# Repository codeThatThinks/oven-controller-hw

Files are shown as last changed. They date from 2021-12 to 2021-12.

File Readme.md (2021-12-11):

# MLL Electronics Oven Controller v1.0

A Raspberry Pi Zero-powered PID reflow oven controller -- PCB design files.

## Controller PCBA

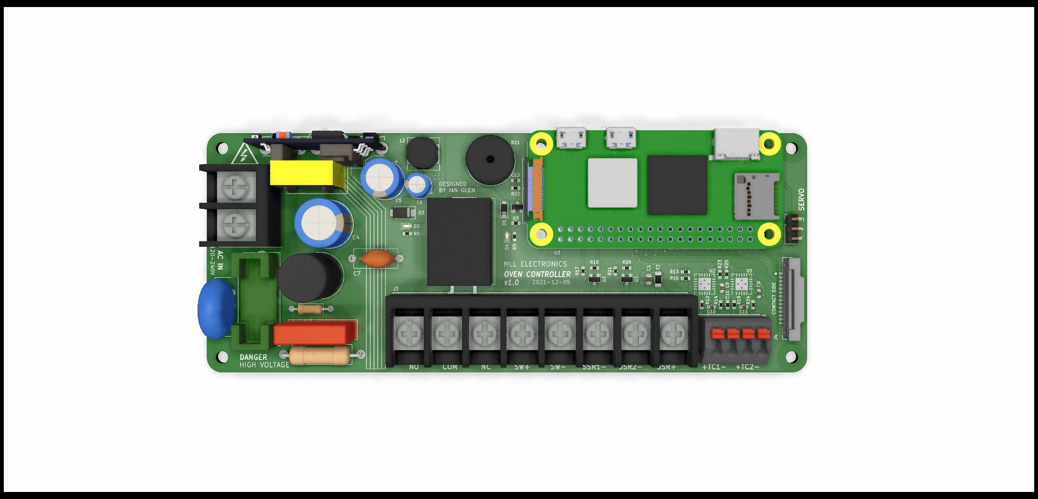
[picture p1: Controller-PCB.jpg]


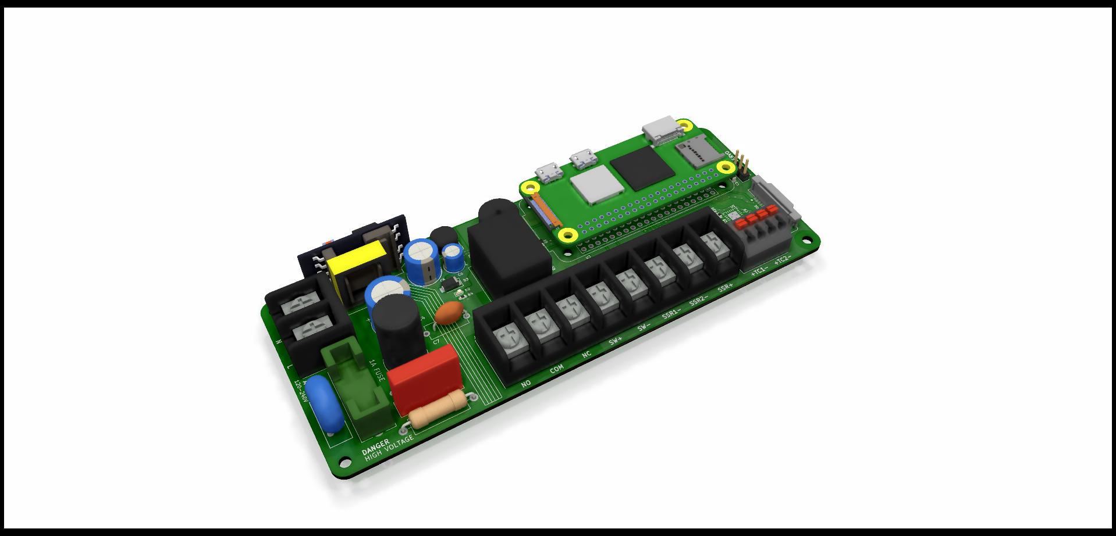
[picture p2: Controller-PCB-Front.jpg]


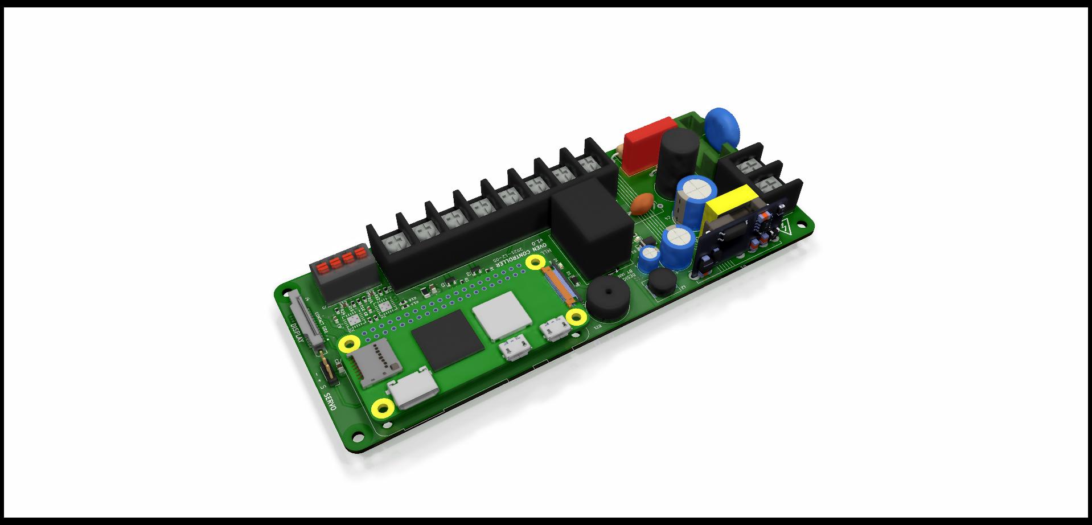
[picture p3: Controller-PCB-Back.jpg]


## Display PCBA

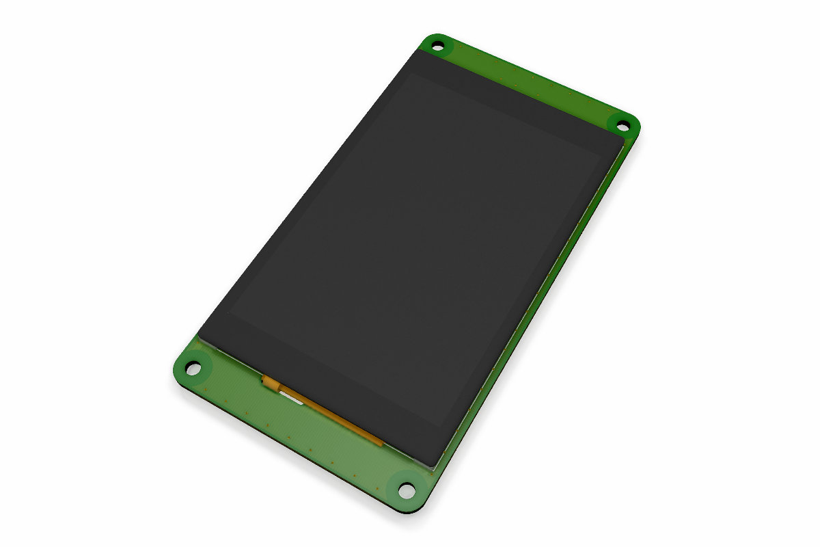
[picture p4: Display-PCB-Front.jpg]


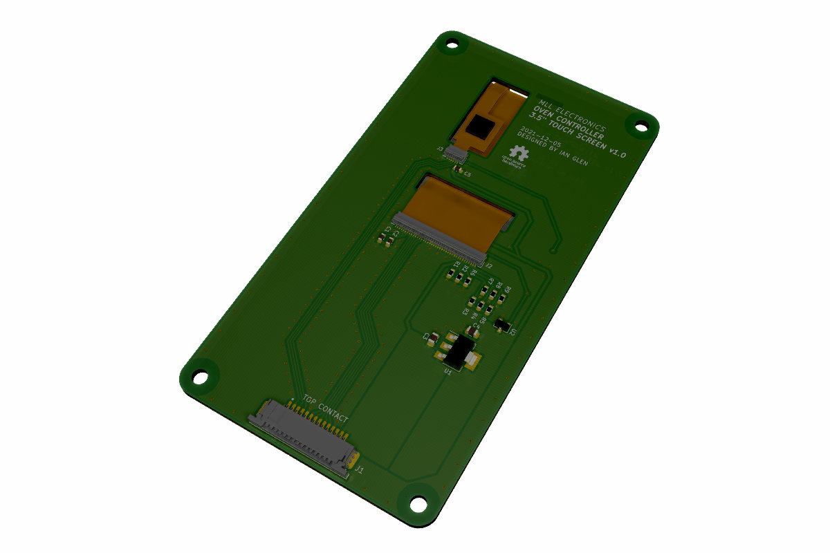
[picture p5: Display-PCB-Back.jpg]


## License

This project is licensed under the CERN-OHL-W v2. See LICENSE for more details.

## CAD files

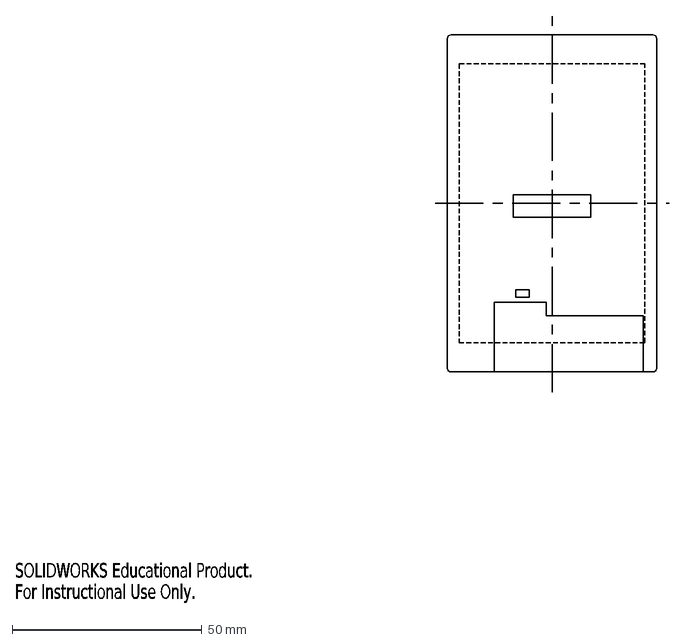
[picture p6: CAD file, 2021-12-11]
solidworks/LiangHaoHai 3.5 IPS TFT CTP Connector Cutout Locations.DXF
SOLIDWORKS Educational Product.
For Instructional Use Only.

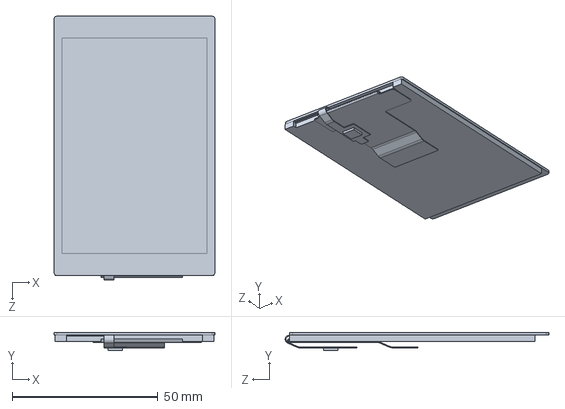
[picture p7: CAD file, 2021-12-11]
solidworks/LiangHaoHai 3.5 IPS TFT CTP.SLDPRT
55.2 x 6.20 x 90.4 mm

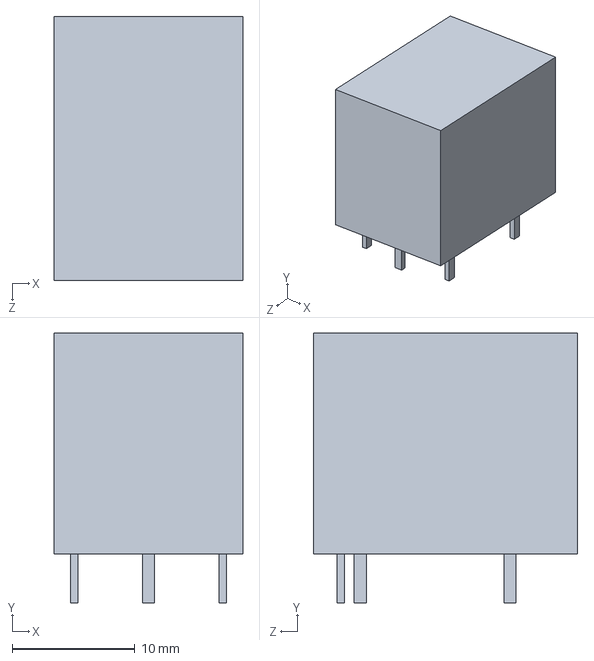
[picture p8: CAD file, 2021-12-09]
solidworks/Relay_SPDT_Omron-G5LE-1.SLDPRT
15.4 x 22.0 x 21.5 mm

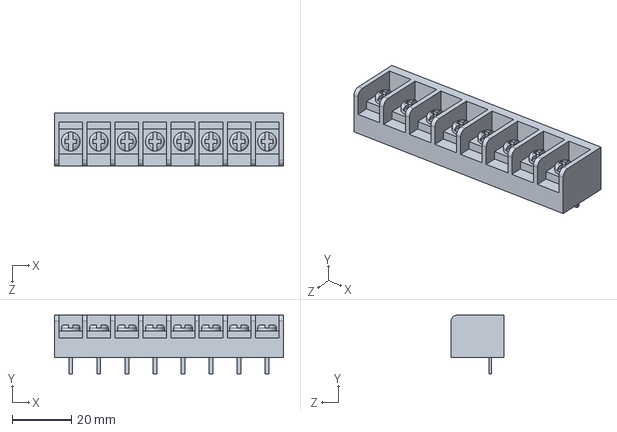
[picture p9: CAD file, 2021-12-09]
solidworks/TerminalBlock_OST_OSTYK44108030_P9.50mm.SLDPRT
77.4 x 19.9 x 17.9 mm

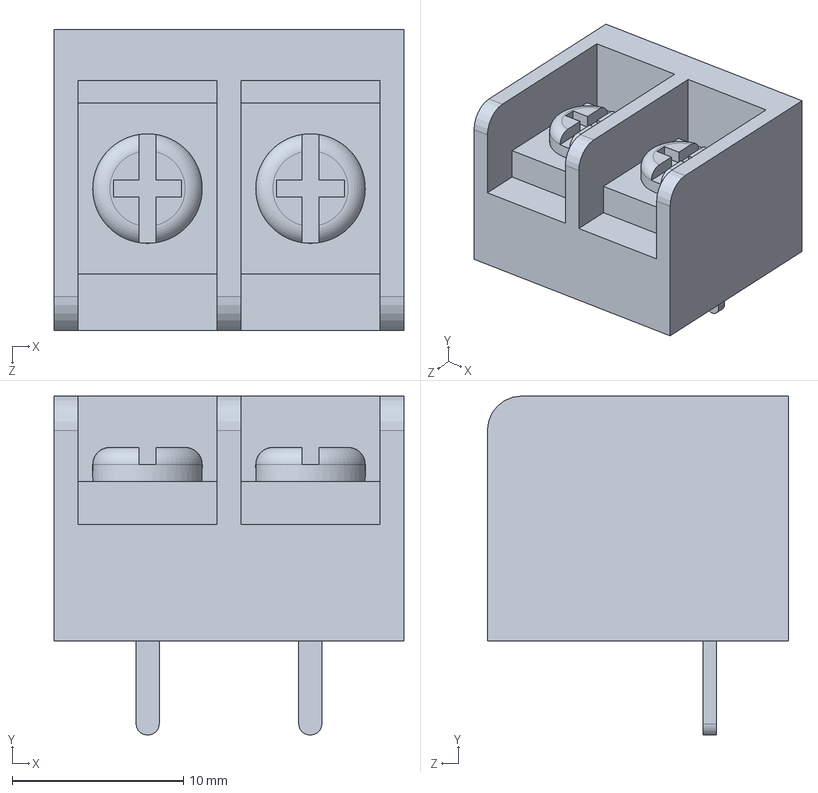
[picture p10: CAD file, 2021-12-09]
solidworks/TerminalBlock_Amphenol_YK-44102_P9.50mm.SLDPRT
20.4 x 19.8 x 17.6 mm

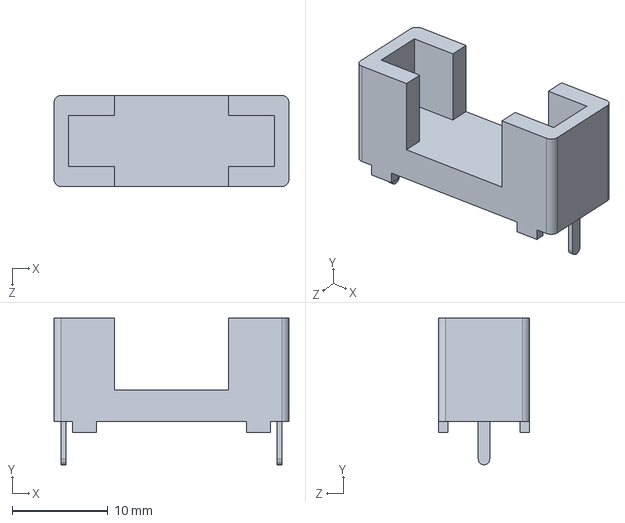
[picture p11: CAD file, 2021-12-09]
solidworks/Fuseholder_Cylinder-5x20mm_Littelfuse_0PTF0078P.SLDPRT
24.5 x 15.3 x 9.50 mm

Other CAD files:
solidworks/LiangHaoHai 3.5 IPS TFT CTP.DXF
solidworks/LiangHaoHai 3.5 IPS TFT CTP.SLDDRW

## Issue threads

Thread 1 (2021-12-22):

SCK and DC pins are swapped on display

codeThatThinks, 2021-12-22:
The pinout on the AliExpress listing has a typo. On the 40-pin FPC, pin 10 should be `RS/SPI_A0` and pin 11 should be `WR/SPI_SCK`.

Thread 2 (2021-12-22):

Increase PCB cutout around CTP FPC cable

codeThatThinks, 2021-12-22:
Increase clearance of the PCB cutout on the display by about 1mm on the right side (looking from the back side of the board). Left side clearance can be decreased by 0.5mm.

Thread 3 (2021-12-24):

Missing EEPROM address 0x30 on schematic

codeThatThinks, 2021-12-24:
AT34C04 eeprom also responds to 0x30 address for write protected writes. No conflict with other devices, but it is missing from the schematic.

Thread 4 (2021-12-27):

Wrong I2C addresses listed on schematic for MCP9601

codeThatThinks, 2021-12-27:
Addresses should be `1100 000x` (0x60) and `1100 001x` (0x61)

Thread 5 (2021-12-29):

MCP960x won't work on hardware I2C busses due to clock stretching bug

codeThatThinks, 2021-12-29:
MCP960x requires clock stretching for all register operations. Pi Zero 2 W has the same SoC as the Pi 3 and therefore does not properly implement clock stretching on hardware I2C busses. MCP960x should be put on its own bitbanged I2C bus using `i2c-gpio`. Use GPIO15 and GPIO18. External 4.7k pullups need to be added on those pins.

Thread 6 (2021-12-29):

Switch EEPROM out for NOR flash for non-volatile storage

codeThatThinks, 2021-12-29:
User settings were supposed to be stored on the I2C EEPROM, however the AT34 does not use the same addressing scheme as the AT24, therefore the kernel driver can only access the first 2KB. The driver also does not support mounting as a block device. A larger NOR flash could be placed on SPI1 and have the same write cycle life but be mountable as a /dev/mtd* device.

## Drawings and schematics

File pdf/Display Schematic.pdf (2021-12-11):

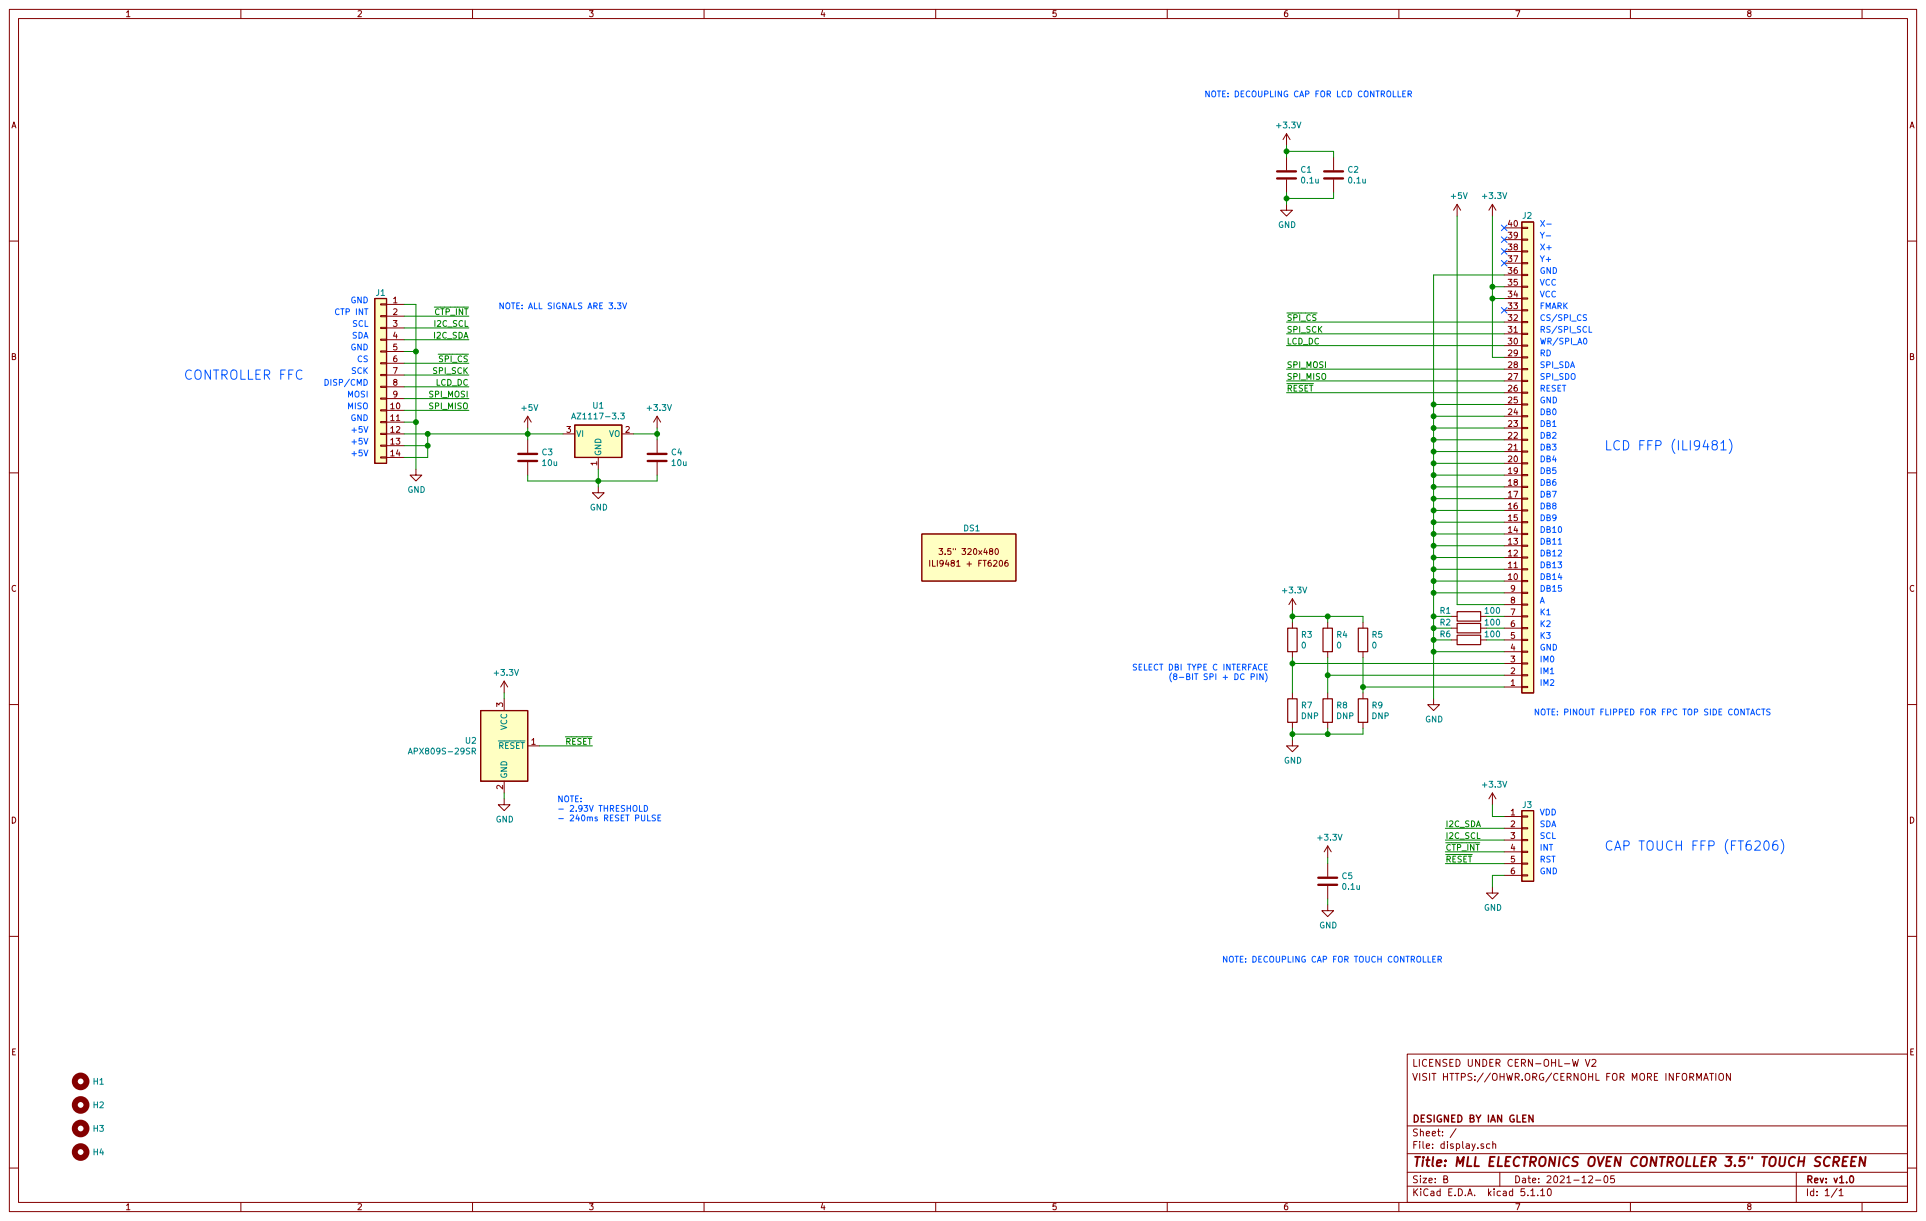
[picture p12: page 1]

DB6 GND GND MOSI MISO
CTP INT SDA

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
NOTE: DECOUPLING CAP FOR TOUCH CONTROLLER

LICENSED UNDER CERN-OHL-W V2
VISIT HTTPS://OHWR.ORG/CERNOHL FOR MORE INFORMATION

File: display.sch Sheet: / DESIGNED BY IAN GLEN

Id: 1/1 Title: MLL ELECTRONICS OVEN CONTROLLER 3.5" TOUCH SCREEN

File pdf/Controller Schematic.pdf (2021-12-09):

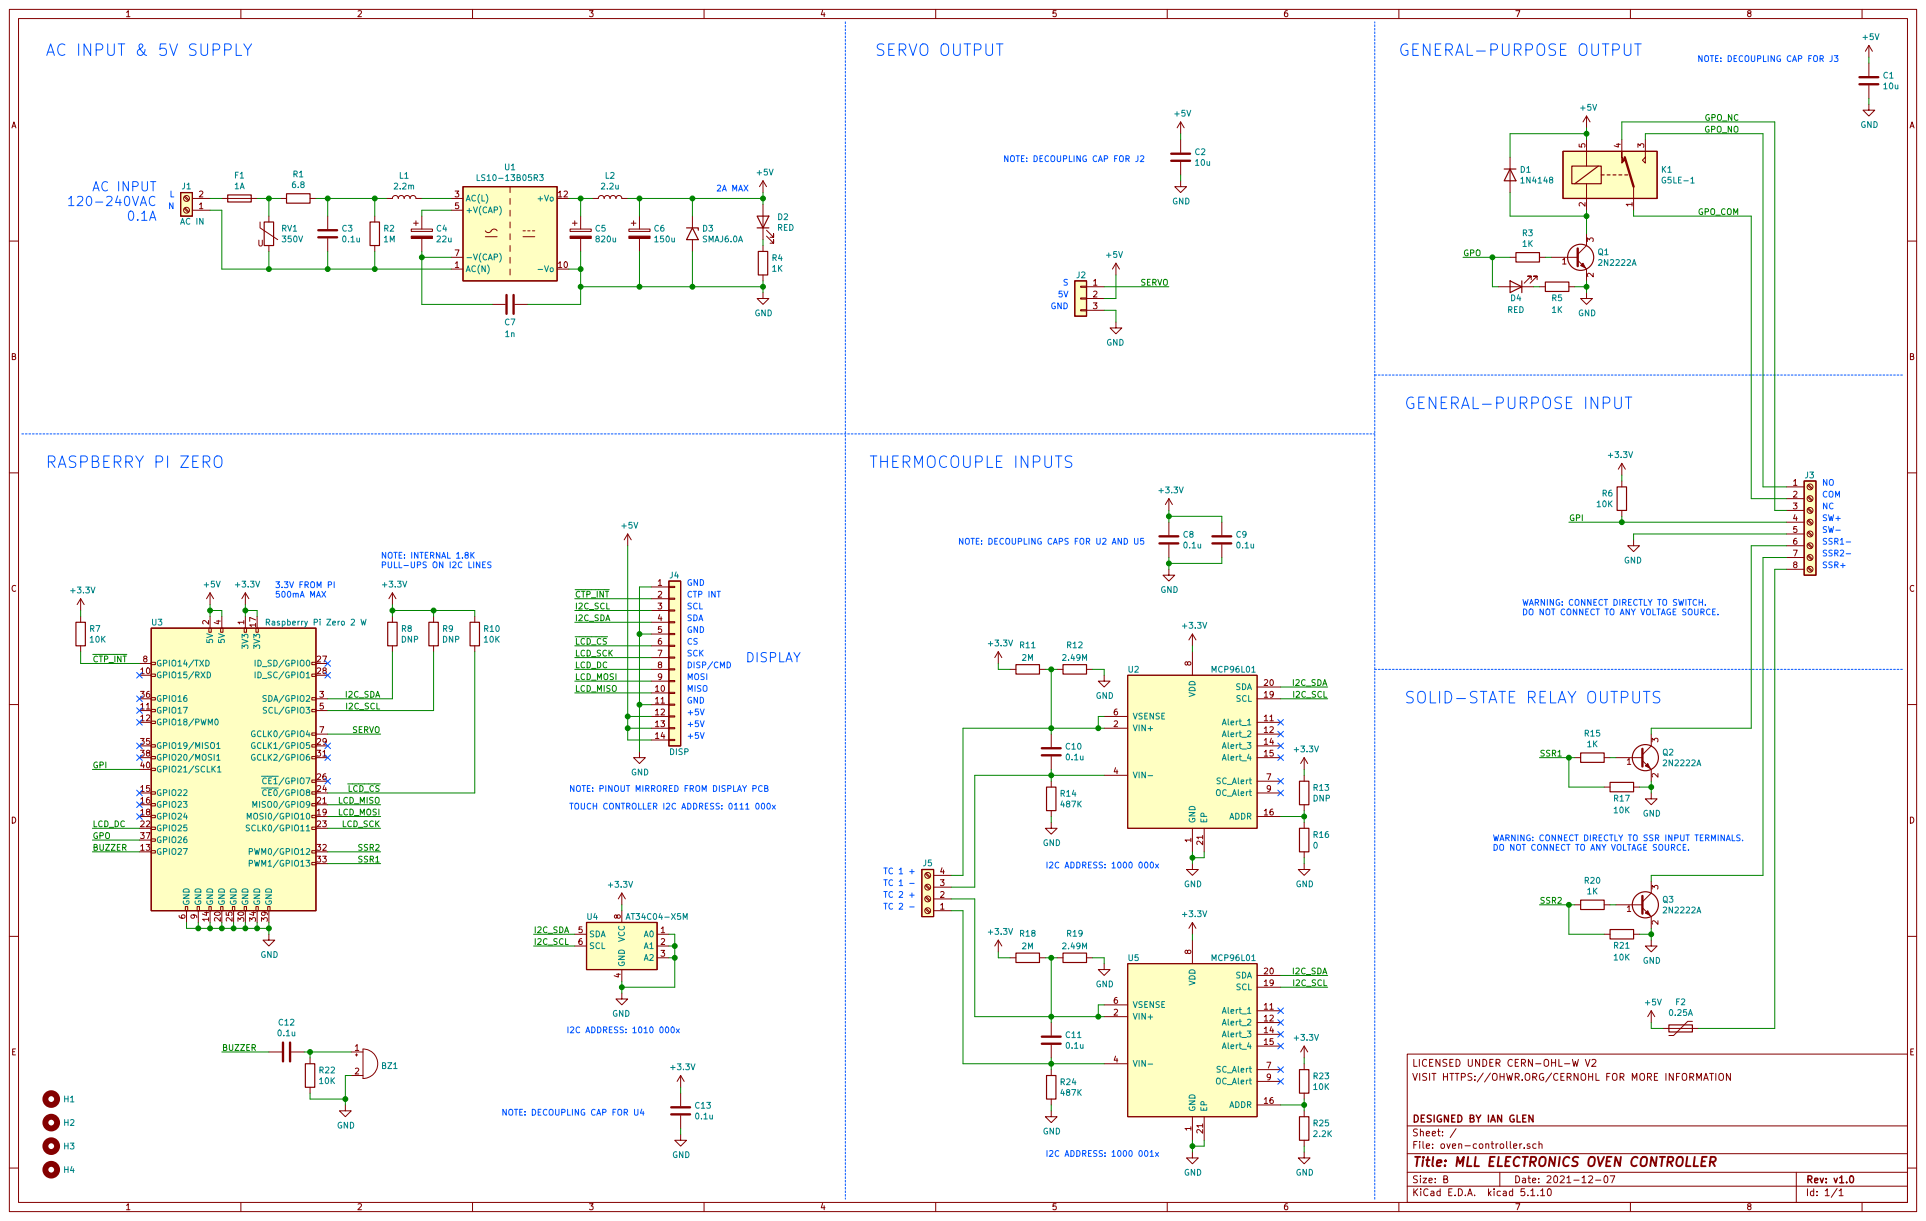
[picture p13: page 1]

NOTE: DECOUPLING CAP FOR J2

TOUCH CONTROLLER I2C ADDRESS: 0111 000x RASPBERRY PI ZERO

NOTE: INTERNAL 1.8K
PULL-UPS ON I2C LINES

1 Alert_1 11 Alert_2 12 Alert_3 14 Alert_4 15 ADDR 16 SCL 19 VIN+ 2 SDA 20 VIN- 4 VSENSE 6 SC_Alert 7 VDD

SOLID-STATE RELAY OUTPUTS

13
14

LICENSED UNDER CERN-OHL-W V2
VISIT HTTPS://OHWR.ORG/CERNOHL FOR MORE INFORMATION

File: oven-controller.sch Sheet: / DESIGNED BY IAN GLEN

Id: 1/1 Title: MLL ELECTRONICS OVEN CONTROLLER

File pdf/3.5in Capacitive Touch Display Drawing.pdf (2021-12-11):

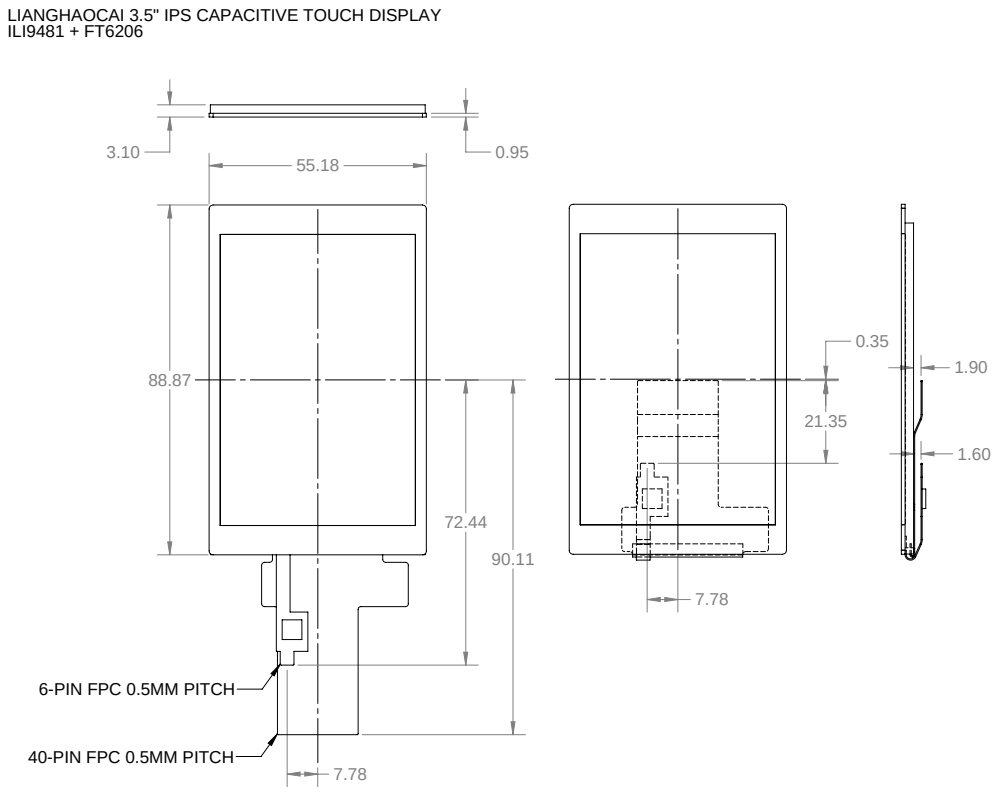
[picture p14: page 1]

LIANGHAOCAI 3.5" IPS CAPACITIVE TOUCH DISPLAY
ILI9481 + FT6206

6-PIN FPC 0.5MM PITCH

40-PIN FPC 0.5MM PITCH

CONNECTOR AND CUTOUT LOCATIONS

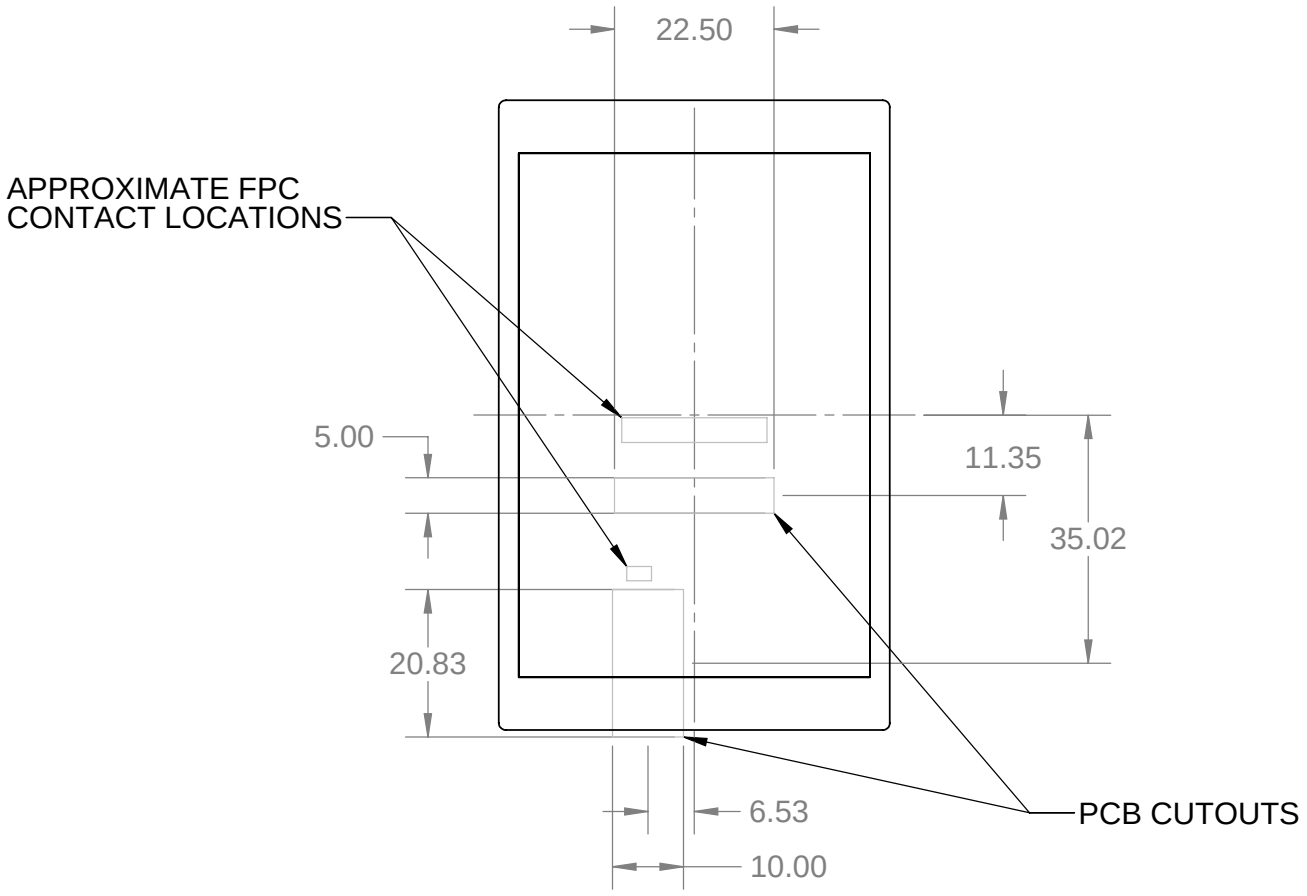
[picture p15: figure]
PCB CUTOUTS; APPROXIMATE FPC CONTACT LOCATIONS

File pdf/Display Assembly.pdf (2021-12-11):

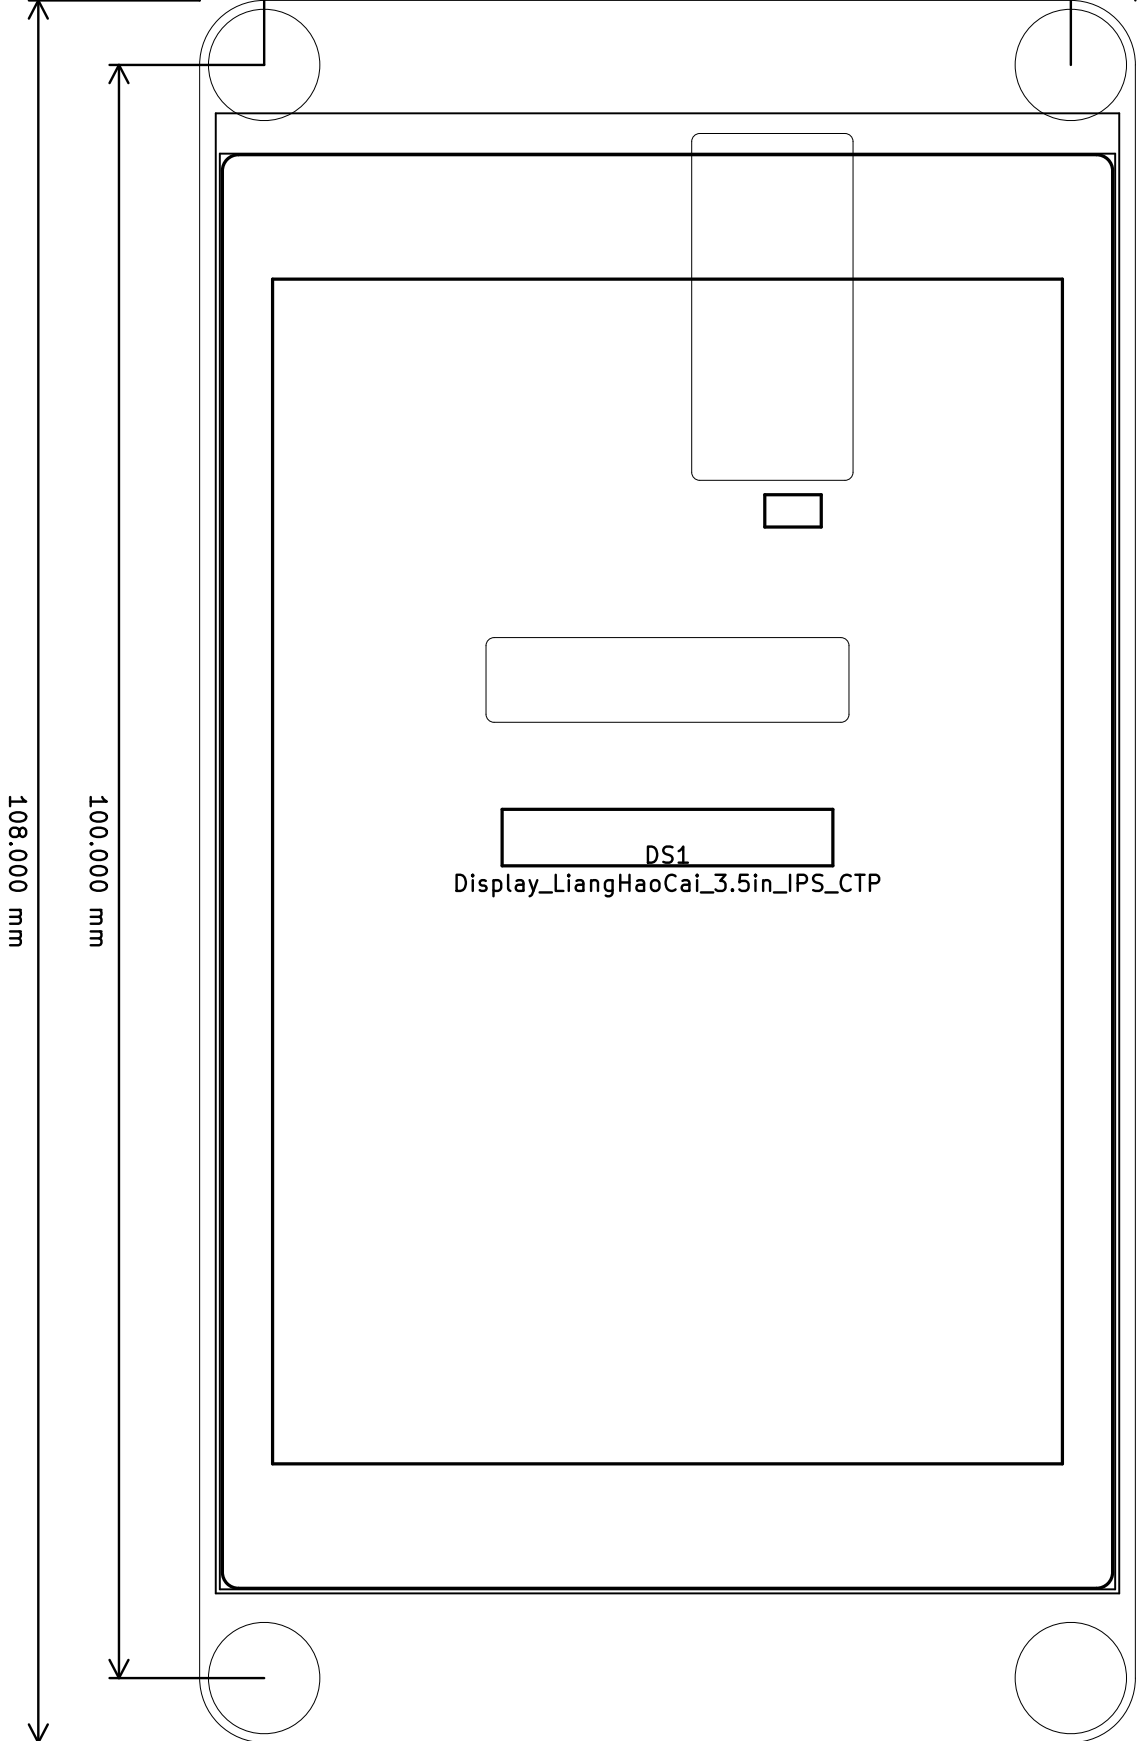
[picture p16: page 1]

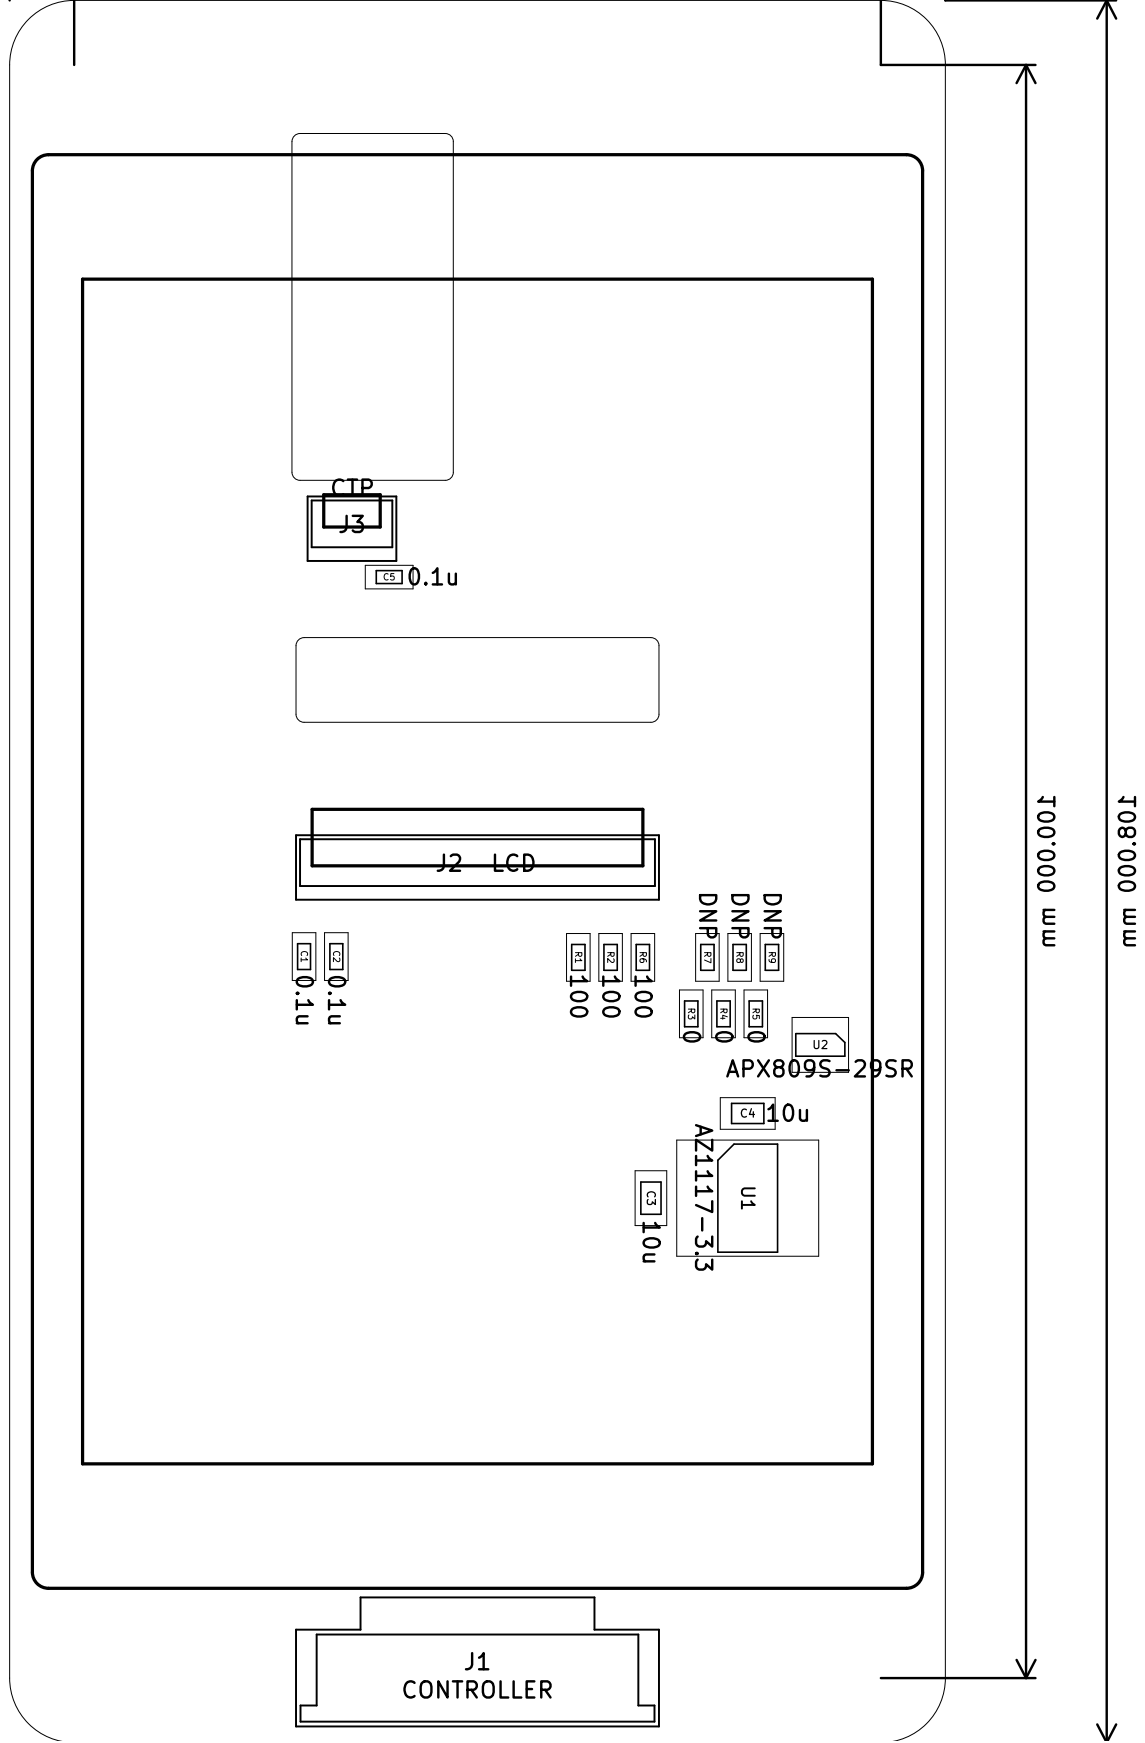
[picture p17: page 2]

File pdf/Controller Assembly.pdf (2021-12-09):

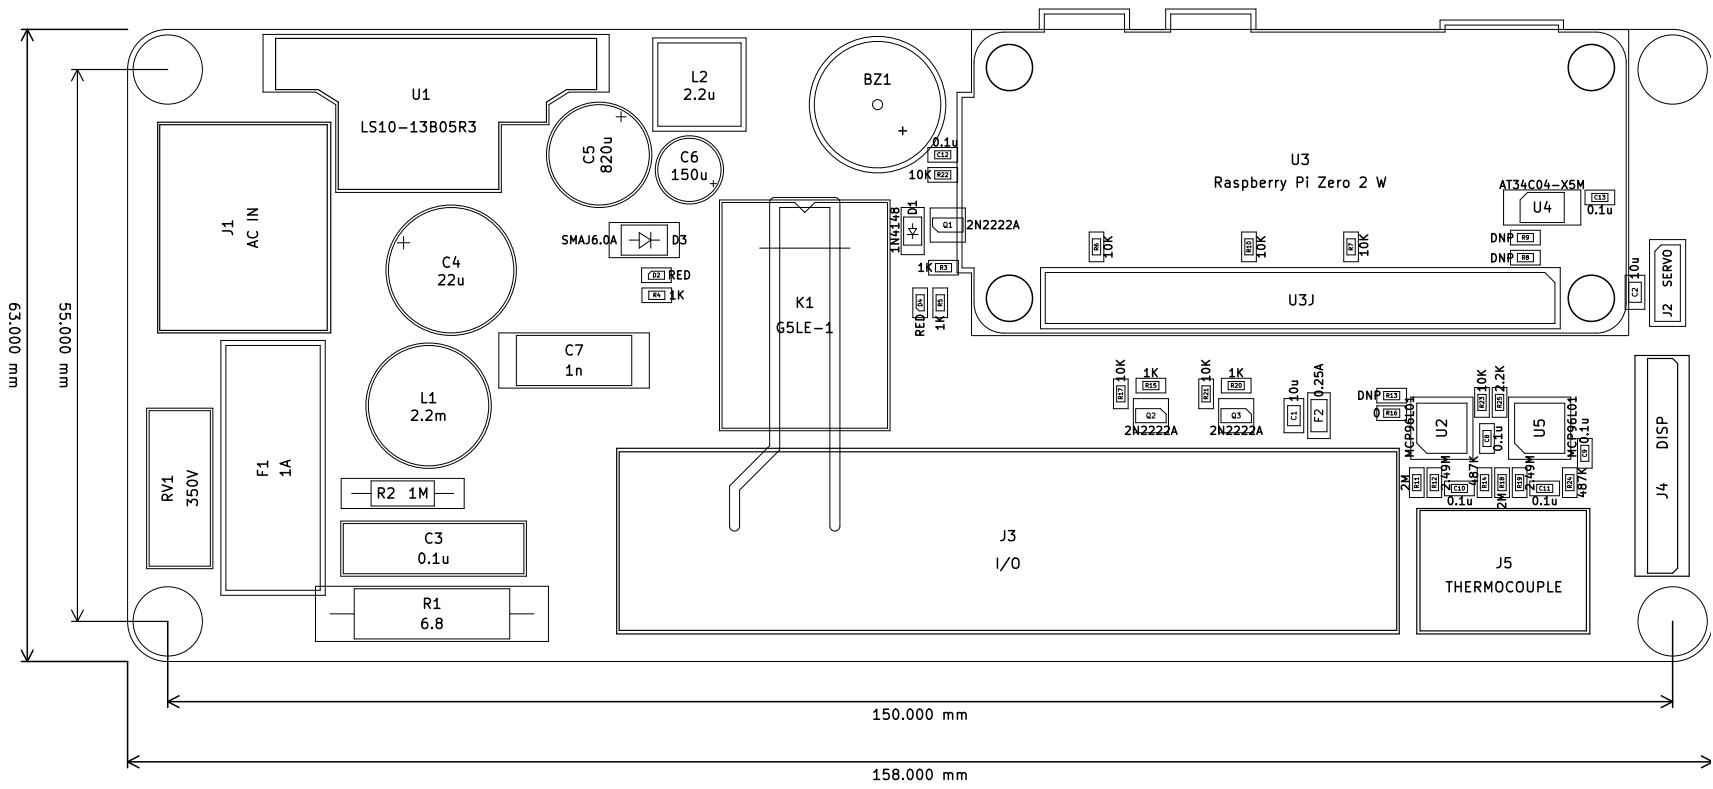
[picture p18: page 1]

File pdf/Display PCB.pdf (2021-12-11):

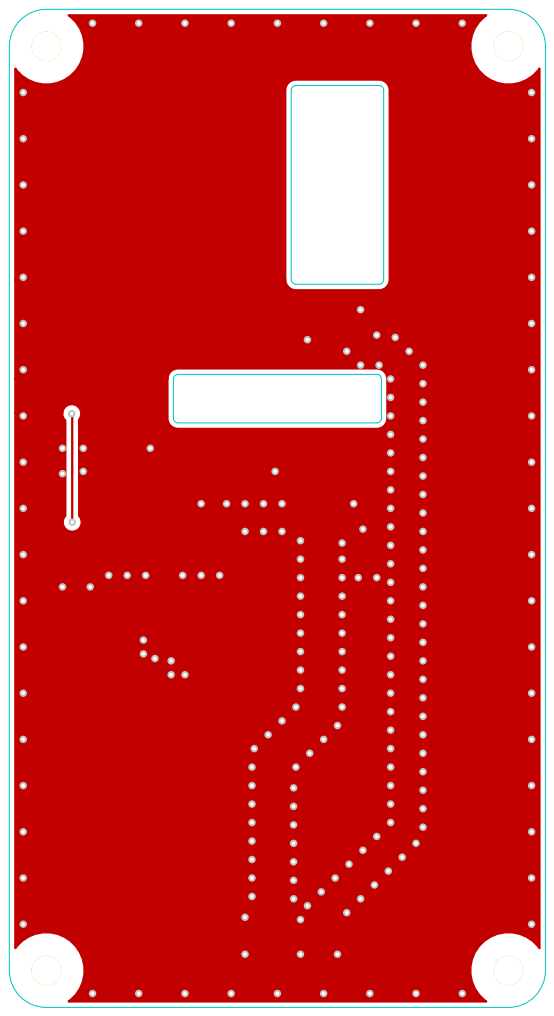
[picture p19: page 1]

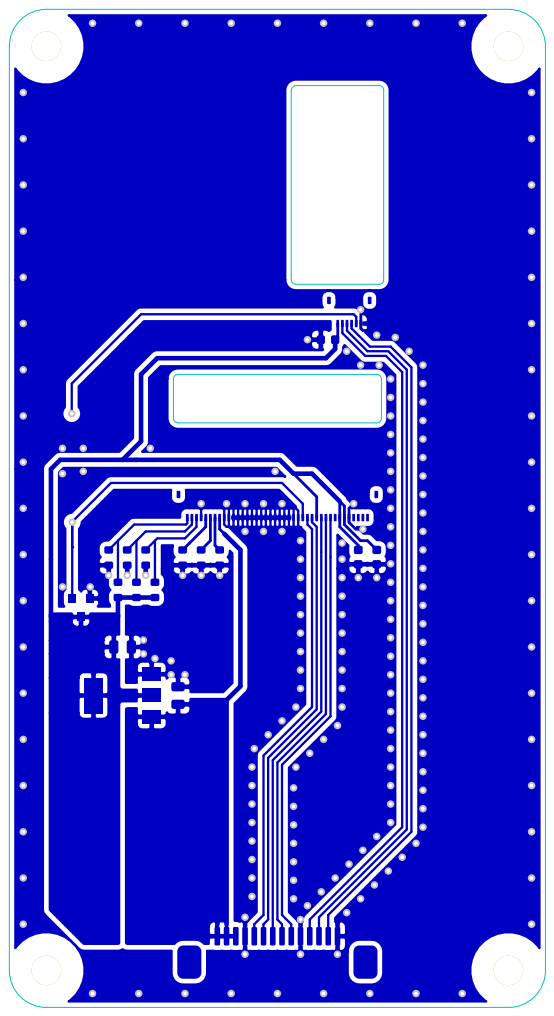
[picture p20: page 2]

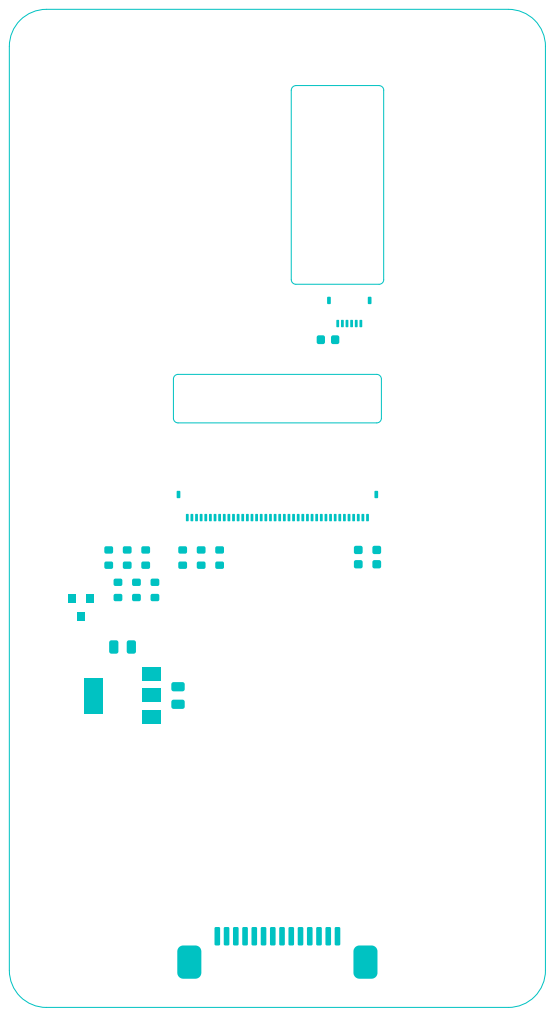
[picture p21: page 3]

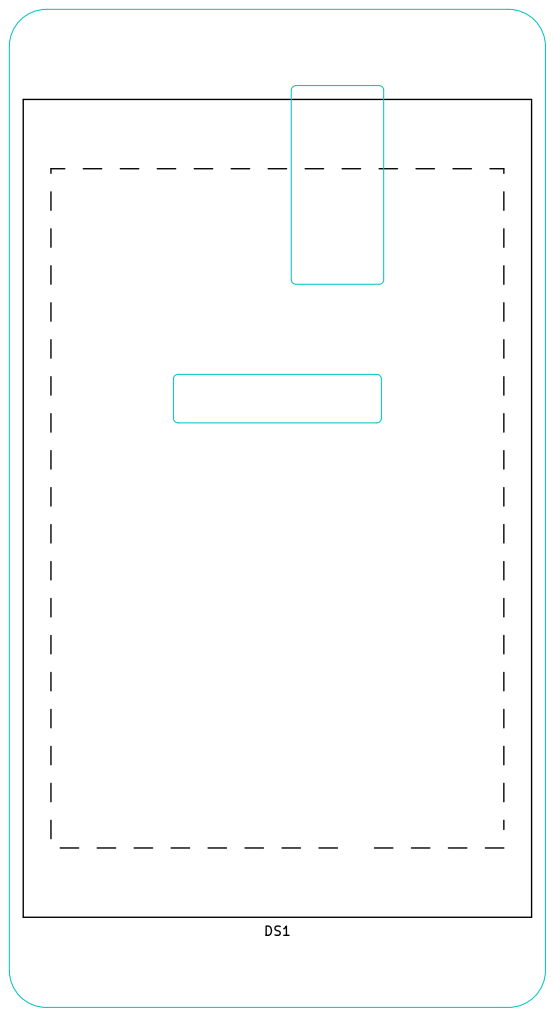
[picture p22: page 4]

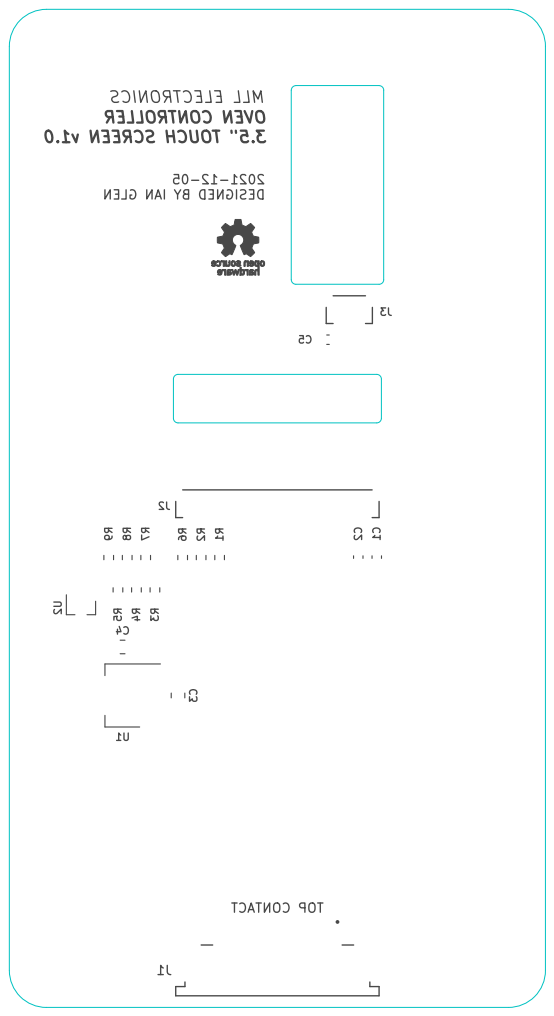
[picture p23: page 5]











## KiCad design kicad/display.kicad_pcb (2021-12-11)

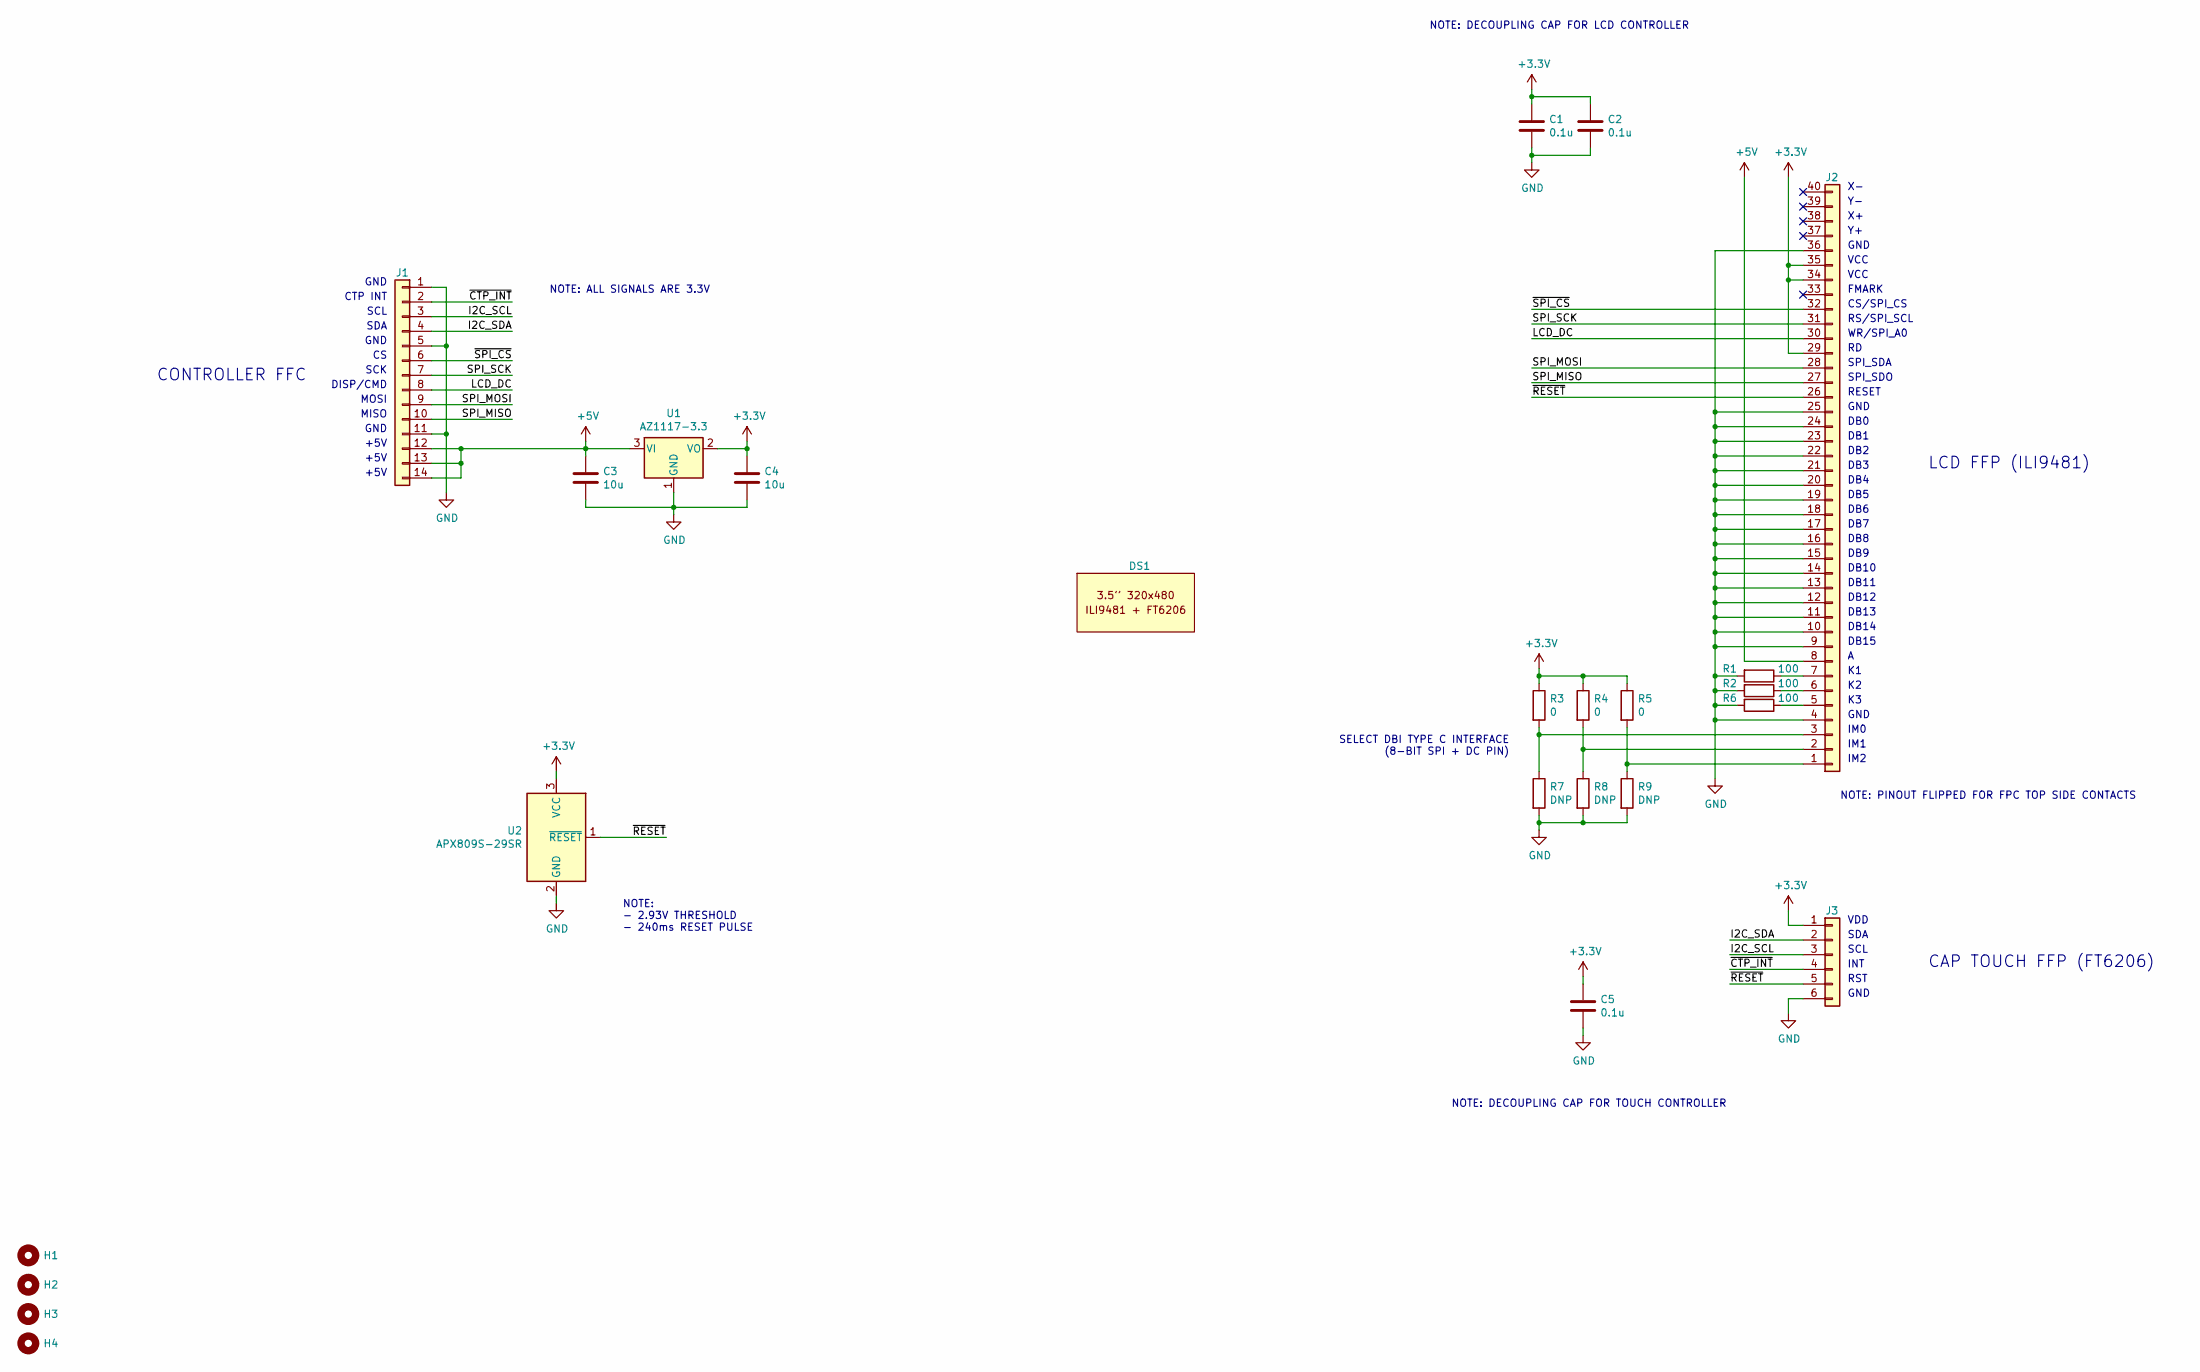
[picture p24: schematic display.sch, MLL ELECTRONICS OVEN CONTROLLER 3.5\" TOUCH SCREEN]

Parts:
C1, C2, C5: 0.1u; C_0603_1608Metric
C3, C4: 10u; C_0805_2012Metric
DS1: Display_LiangHaoCai_3.5in_IPS_CTP
H1, H2, H3, H4: MountingHole; MountingHole_3.2mm_M3
J1: CONTROLLER; TE_1-84953-4_1x14_1MP_P1.0_Horizontal
J2: LCD; GCT_FFC2B28-40-G_1x40_1MP_P0.50mm_Horizontal
J3: CTP; GCT_FFC2B28-06-G_1x6_1MP_P0.50mm_Horizontal
R1, R2, R6: 100; R_0603_1608Metric
R3, R4, R5: 0; R_0603_1608Metric
R7, R8, R9: DNP; R_0603_1608Metric
U1: AZ1117-3.3; SOT-223-3_TabPin2
U2: APX809S-29SR; SOT-23

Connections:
+3V3: C1.1, C2.1, C4.1, C5.1, J2.29, J2.34, J2.35, J3.1, R3.1, R4.1, R5.1, U1.2 (VO), U2.3 (VCC)
+5V: C3.1, J1.12, J1.13, J1.14, J2.8, U1.3 (VI)
/I2C_SCL: J1.3, J3.3
/I2C_SDA: J1.4, J3.2
/LCD_DC: J1.8, J2.30
/SPI_MISO: J1.10, J2.27
/SPI_MOSI: J1.9, J2.28
/SPI_SCK: J1.7, J2.31
/~CTP_INT: J1.2, J3.4
/~RESET: J2.26, J3.5, U2.1 (~RESET)
/~SPI_CS: J1.6, J2.32
GND: C1.2, C2.2, C3.2, C4.2, C5.2, J1.1, J1.5, J1.11, J2.4, J2.9, J2.10, J2.11, J2.12, J2.13, J2.14, J2.15, J2.16, J2.17, J2.18, J2.19, J2.20, J2.21, J2.22, J2.23, J2.24, J2.25, J2.36, J3.6, R1.2, R2.2, R6.2, R7.2, R8.2, R9.2, U1.1 (GND), U2.2 (GND)
unnamed: J2.1, R5.2, R9.1
unnamed: J2.2, R4.2, R8.1
unnamed: J2.3, R3.2, R7.1
unnamed: J2.5, R6.1
unnamed: J2.6, R2.1
unnamed: J2.7, R1.1

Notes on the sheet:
GND
VCC
FMARK
CS/SPI_CS
RS/SPI_SCL
WR/SPI_A0
SPI_SDA
SPI_SDO
RESET
DB0
DB1
DB2
DB3
DB4
DB5
DB6
DB7
DB8
DB9
DB10
DB11
DB12
DB13
DB14
DB15
IM0
IM1
IM2
LCD FFP (ILI9481)
CAP TOUCH FFP (FT6206)
VDD
SDA
SCL
INT
RST
NOTE: DECOUPLING CAP FOR LCD CONTROLLER
NOTE: DECOUPLING CAP FOR TOUCH CONTROLLER
NOTE: - 2.93V THRESHOLD - 240ms RESET PULSE
SCK
MOSI

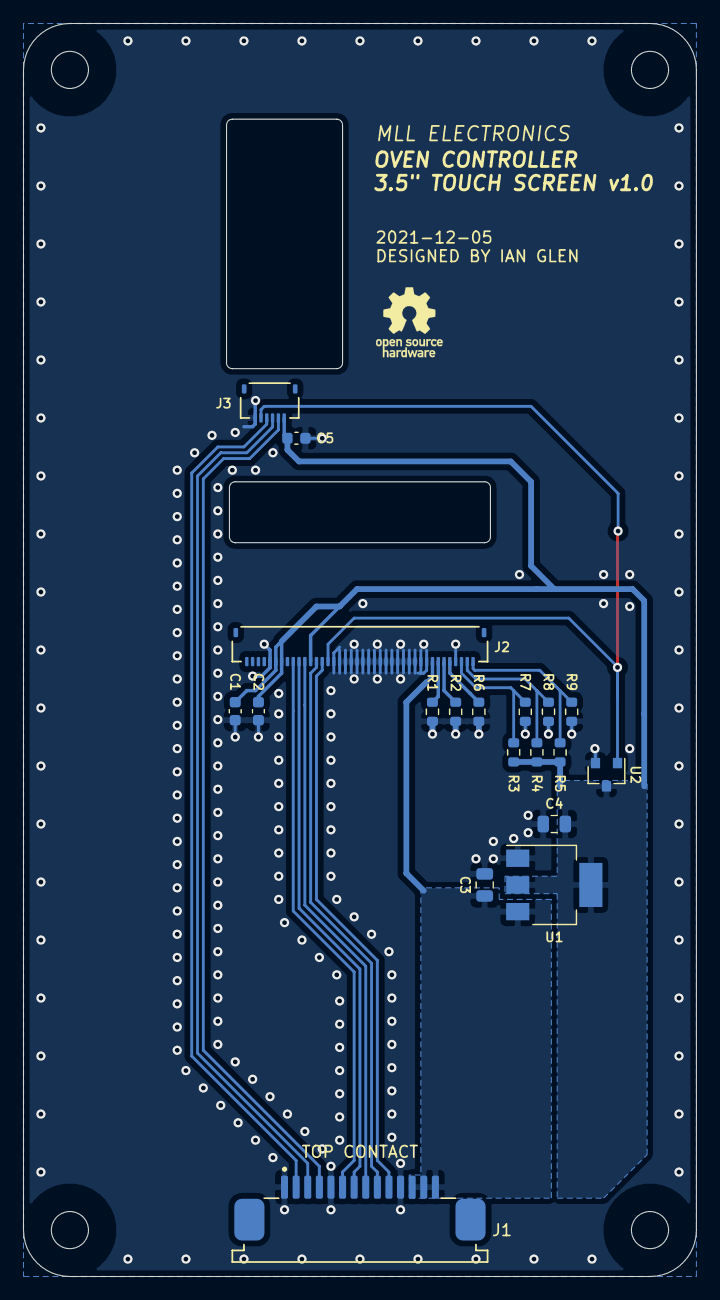
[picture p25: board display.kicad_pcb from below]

Board: 2 copper layers, 58.0 x 108.0 mm, 24 parts (19 on the bottom side), 18 nets.

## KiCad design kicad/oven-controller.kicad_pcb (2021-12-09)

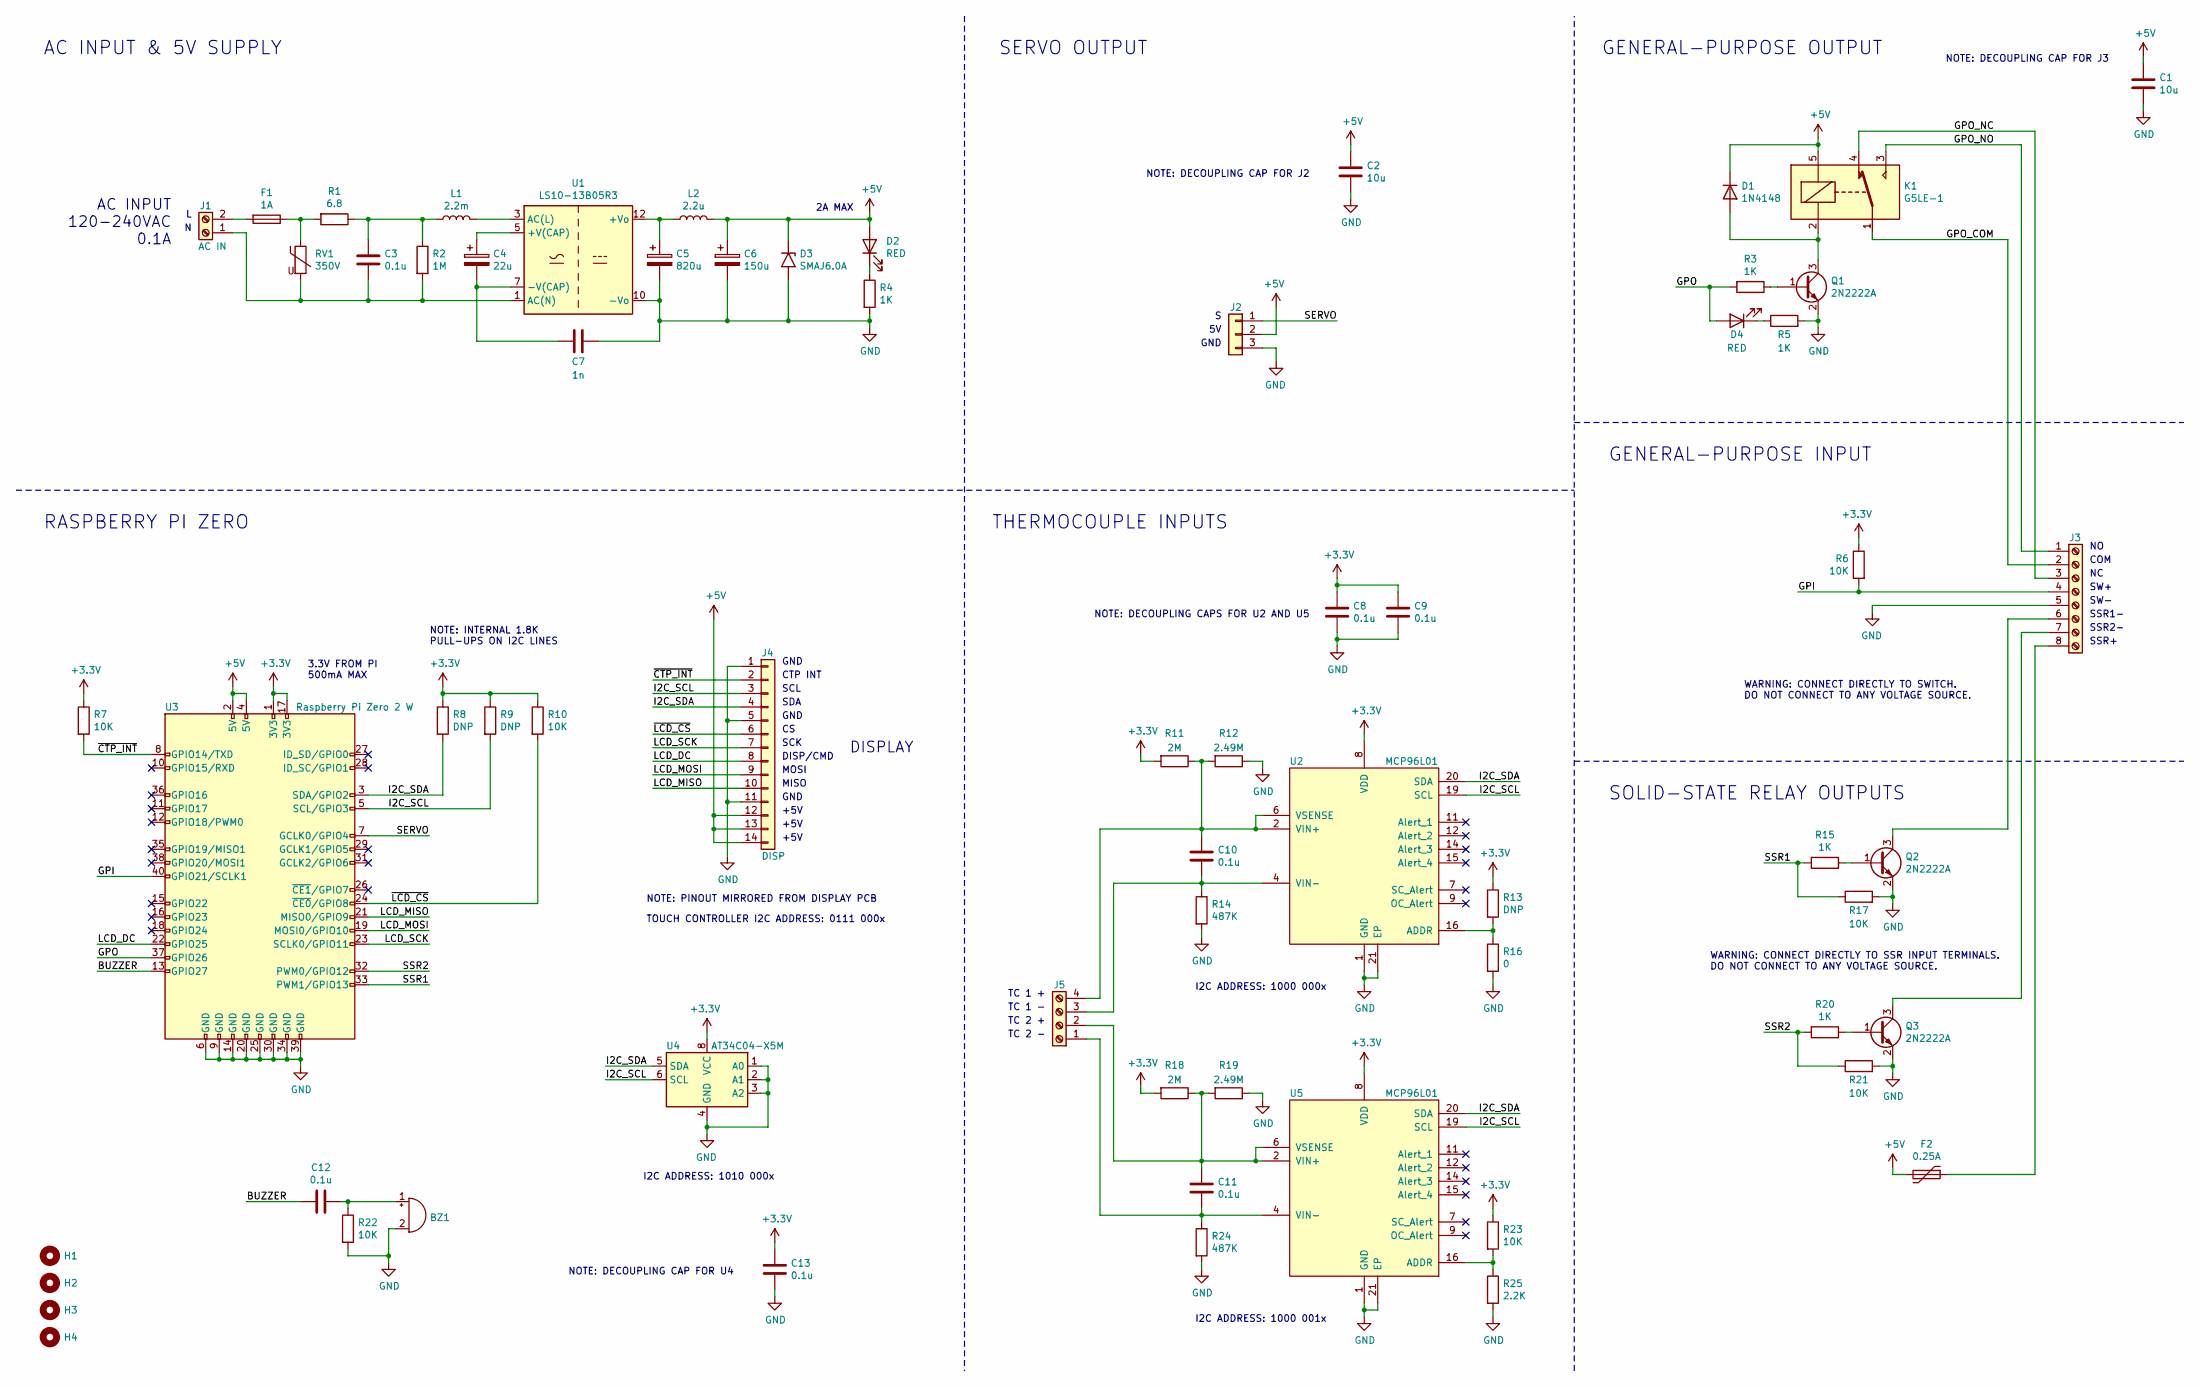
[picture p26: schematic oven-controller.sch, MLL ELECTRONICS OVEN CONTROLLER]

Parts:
BZ1: Buzzer; Buzzer_Murata_PKM13EPYH4002-B0
C1, C2: 10u; C_0805_2012Metric
C3: 0.1u; C_Rect_L18.0mm_W5.0mm_P15.00mm_FKS3_FKP3
C4: 22u; CP_Radial_D12.5mm_P5.00mm
C5: 820u; CP_Radial_D10.0mm_P5.00mm
C6: 150u; CP_Radial_D6.3mm_P2.50mm
C7: 1n; C_Disc_D9.0mm_W5.0mm_P12.50mm
C8, C9, C10, C11, C12, C13: 0.1u; C_0603_1608Metric
D1: 1N4148; D_SOD-123
D2, D4: RED; LED_0603_1608Metric
D3: SMAJ6.0A; D_SMA
F1: 1A; Fuseholder_Cylinder-5x20mm_Littelfuse_0PTF0078P
F2: 0.25A; Fuse_1206_3216Metric
H1, H2, H3, H4: MountingHole; MountingHole_3.2mm_M3
J1: AC IN; TerminalBlock_Amphenol_YK-44102_P9.50mm
J2: SERVO; PinHeader_1x03_P2.54mm_Vertical
J3: I/O; TerminalBlock_OST_OSTYK44108030_P9.50mm
J4: DISP; TE_1-1734248-4_1x14_1MP_P1.0_Vertical
J5: THERMOCOUPLE; TerminalBlock_Wuerth_691412320004_P3.81mm
K1: G5LE-1; Relay_SPDT_Omron-G5LE-1
L1: 2.2m; L_Radial_D12.0mm_P6.00mm_MuRATA_1900R
L2: 2.2u; L_Murata_DG8040C
Q1, Q2, Q3: 2N2222A; SOT-23
R1: 6.8; R_Axial_DIN0516_L15.5mm_D5.0mm_P20.32mm_Horizontal
R2: 1M; R_Axial_DIN0207_L6.3mm_D2.5mm_P10.16mm_Horizontal
R3, R4, R5, R15, R20: 1K; R_0603_1608Metric
R6, R7, R10, R17, R21, R22, R23: 10K; R_0603_1608Metric
R8, R9, R13: DNP; R_0603_1608Metric
R11, R18: 2M; R_0603_1608Metric
R12, R19: 2.49M; R_0603_1608Metric
R14, R24: 487K; R_0603_1608Metric
R16: 0; R_0603_1608Metric
R25: 2.2K; R_0603_1608Metric
RV1: 350V; RV_Disc_D15.5mm_W6.1mm_P7.5mm
U1: LS10-13B05R3; Converter_ACDC_CUI_PBO-xxC-x_THT_Vertical
U2, U5: MCP96L01; TQFN-20-1EP_5x5mm_P0.65mm_EP3.25x3.25mm
U3: Raspberry Pi Zero 2 W; Raspberry_Pi_Zero_Socketed_THT_FaceUp_MountingHoles
U4: AT34C04-X5M; TSSOP-8_4.4x3mm_P0.65mm

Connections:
+3V3: C8.1, C9.1, C13.1, R6.1, R7.1, R8.1, R9.1, R10.1, R11.2, R13.1, R18.2, R23.1, U2.8 (VDD), U3.1 (3V3), U3.17 (3V3), U4.8 (VCC), U5.8 (VDD)
+5V: C1.1, C2.1, C6.1, D1.1 (K), D2.2 (A), D3.1 (A1), F2.2, J2.2, J4.12, J4.13, J4.14, K1.5, L2.2, U3.2 (5V), U3.4 (5V)
/BUZZER: C12.2, U3.13 (GPIO27)
/GPI: J3.4, R6.2, U3.40 (GPIO21/SCLK1)
/GPO: D4.2 (A), R3.2, U3.37 (GPIO26)
/GPO_COM: J3.2, K1.1
/GPO_NC: J3.3, K1.4
/GPO_NO: J3.1, K1.3
/I2C_SCL: J4.3, R9.2, U2.19 (SCL), U3.5 (SCL/GPIO3), U4.6 (SCL), U5.19 (SCL)
/I2C_SDA: J4.4, R8.2, U2.20 (SDA), U3.3 (SDA/GPIO2), U4.5 (SDA), U5.20 (SDA)
/LCD_DC: J4.8, U3.22 (GPIO25)
/LCD_MISO: J4.10, U3.21 (MISO0/GPIO9)
/LCD_MOSI: J4.9, U3.19 (MOSI0/GPIO10)
/LCD_SCK: J4.7, U3.23 (SCLK0/GPIO11)
/SERVO: J2.1, U3.7 (GCLK0/GPIO4)
/SSR1: R15.2, R17.1, U3.33 (PWM1/GPIO13)
/SSR2: R20.2, R21.1, U3.32 (PWM0/GPIO12)
/~CTP_INT: J4.2, R7.2, U3.8 (GPIO14/TXD)
/~LCD_CS: J4.6, R10.2, U3.24 (~CE0~/GPIO8)
GND: BZ1.2 (+), C1.2, C2.2, C5.2, C6.2, C7.1, C8.2, C9.2, C13.2, D3.2 (A2), J2.3, J3.5, J4.1, J4.5, J4.11, Q1.2 (E), Q2.2 (E), Q3.2 (E), R4.2, R5.2, R12.1, R14.2, R16.2, R17.2, R19.1, R21.2, R22.2, R24.2, R25.2, U1.10 (-Vo), U2.1 (GND), U2.3 (GND), U2.5 (GND), U2.10 (GND), U2.13 (GND), U2.17 (GND), U2.18 (GND), U2.21 (EP), U3.6 (GND), U3.9 (GND), U3.14 (GND), U3.20 (GND), U3.25 (GND), U3.30 (GND), U3.34 (GND), U3.39 (GND), U4.1 (A0), U4.2 (A1), U4.3 (A2), U4.4 (GND), U5.1 (GND), U5.3 (GND), U5.5 (GND), U5.10 (GND), U5.13 (GND), U5.17 (GND), U5.18 (GND), U5.21 (EP)
unnamed: BZ1.1 (-), C12.1, R22.1
unnamed: C3.1, L1.1, R1.1, R2.1
unnamed: C3.2, J1.1, R2.2, RV1.2, U1.1 (AC(N))
unnamed: C4.1, U1.5 (+V(CAP))
unnamed: C4.2, C7.2, U1.7 (-V(CAP))
unnamed: C5.1, L2.1, U1.12 (+Vo)
unnamed: C10.1, J5.4, R11.1, R12.2, U2.2 (VIN+), U2.6 (VSENSE)
unnamed: C10.2, J5.3, R14.1, U2.4 (VIN-)
unnamed: C11.1, J5.2, R18.1, R19.2, U5.2 (VIN+), U5.6 (VSENSE)
unnamed: C11.2, J5.1, R24.1, U5.4 (VIN-)
unnamed: D1.2 (A), K1.2, Q1.3 (C)
unnamed: D2.1 (K), R4.1
unnamed: D4.1 (K), R5.1
unnamed: F1.1, R1.2, RV1.1
unnamed: F1.2, J1.2
unnamed: F2.1, J3.8
unnamed: J3.6, Q2.3 (C)
unnamed: J3.7, Q3.3 (C)
unnamed: L1.2, U1.3 (AC(L))
unnamed: Q1.1 (B), R3.1
unnamed: Q2.1 (B), R15.1
unnamed: Q3.1 (B), R20.1
unnamed: R13.2, R16.1, U2.16 (ADDR)
unnamed: R23.2, R25.1, U5.16 (ADDR)

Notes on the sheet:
I2C ADDRESS: 1000 000x
NOTE: DECOUPLING CAPS FOR U2 AND U5
THERMOCOUPLE INPUTS
RASPBERRY PI ZERO
AC INPUT & 5V SUPPLY
AC INPUT 120-240VAC 0.1A
2A MAX
3.3V FROM PI 500mA MAX
COM
SOLID-STATE RELAY OUTPUTS
GENERAL-PURPOSE OUTPUT
I2C ADDRESS: 1000 001x
GENERAL-PURPOSE INPUT
WARNING: CONNECT DIRECTLY TO SWITCH. DO NOT CONNECT TO ANY VOLTAGE SOURCE.
I2C ADDRESS: 1010 000x
NOTE: DECOUPLING CAP FOR U4
TOUCH CONTROLLER I2C ADDRESS: 0111 000x
DISPLAY
SCK
MOSI
MISO
DISP/CMD
GND
SCL
SDA
CTP INT
+5V
WARNING: CONNECT DIRECTLY TO SSR INPUT TERMINALS. DO NOT CONNECT TO ANY VOLTAGE SOURCE.
SERVO OUTPUT
SW+
SW-
SSR2-
SSR1-
SSR+
TC 2 -
TC 2 +
TC 1 -
TC 1 +
NOTE: PINOUT MIRRORED FROM DISPLAY PCB
NOTE: DECOUPLING CAP FOR J2

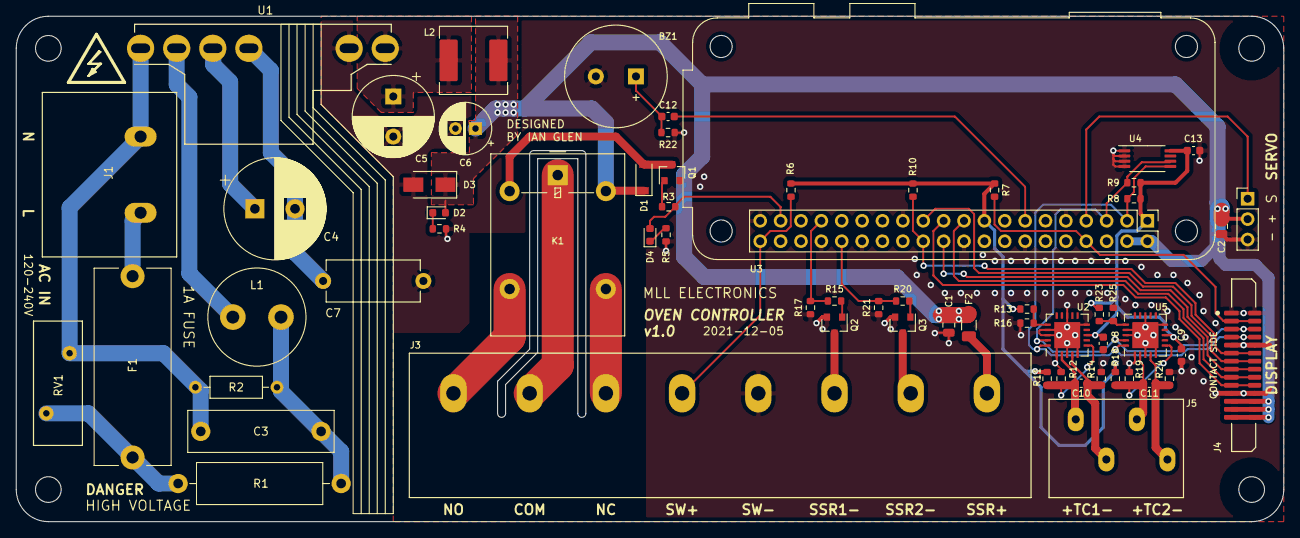
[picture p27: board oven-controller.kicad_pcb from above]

Board: 2 copper layers, 158.0 x 63.0 mm, 66 parts (0 on the bottom side), 44 nets.

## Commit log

2021-12-09 Initial commit of controller PCBA v1.0
    [Fuseholder_Cylinder-5x20mm_Littelfuse_0PTF0078P.SLDPRT, Relay_SPDT_Omron-G5LE-1.SLDPRT, TerminalBlock_Amphenol_YK-44102_P9.50mm.SLDPRT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]
2021-12-11 Initial commit of display PCBA v1.0
    [LiangHaoHai 3.5 IPS TFT CTP Connector Cutout Locations.DXF, LiangHaoHai 3.5 IPS TFT CTP.DXF, LiangHaoHai 3.5 IPS TFT CTP.SLDDRW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]
2021-12-11 Fix PCB images
